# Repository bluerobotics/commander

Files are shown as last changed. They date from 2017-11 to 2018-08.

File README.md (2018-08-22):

# Commander

Blue Robotics Thruster Commander hardware and software: Thruster Test Jig Version.

Acceleration is limited more in this version than is usual.  Changing speed from stopped to full speed takes 2.0 seconds (as opposed to 0.8 seconds for the default firmware).

## Compiling and Uploading

The code can be compiled in the Arduino IDE version 1.0 and above. It requires the `attiny` board plugin by David Mellis, which can be installed with the Arduino Boards Manager. The following compile settings should be used:

- **Board:** ATtiny
- **Processor:** ATtiny84
- **Clock:** 8 Mhz (External)

- **Programmer:** USBTinyISP (or whatever you're using)

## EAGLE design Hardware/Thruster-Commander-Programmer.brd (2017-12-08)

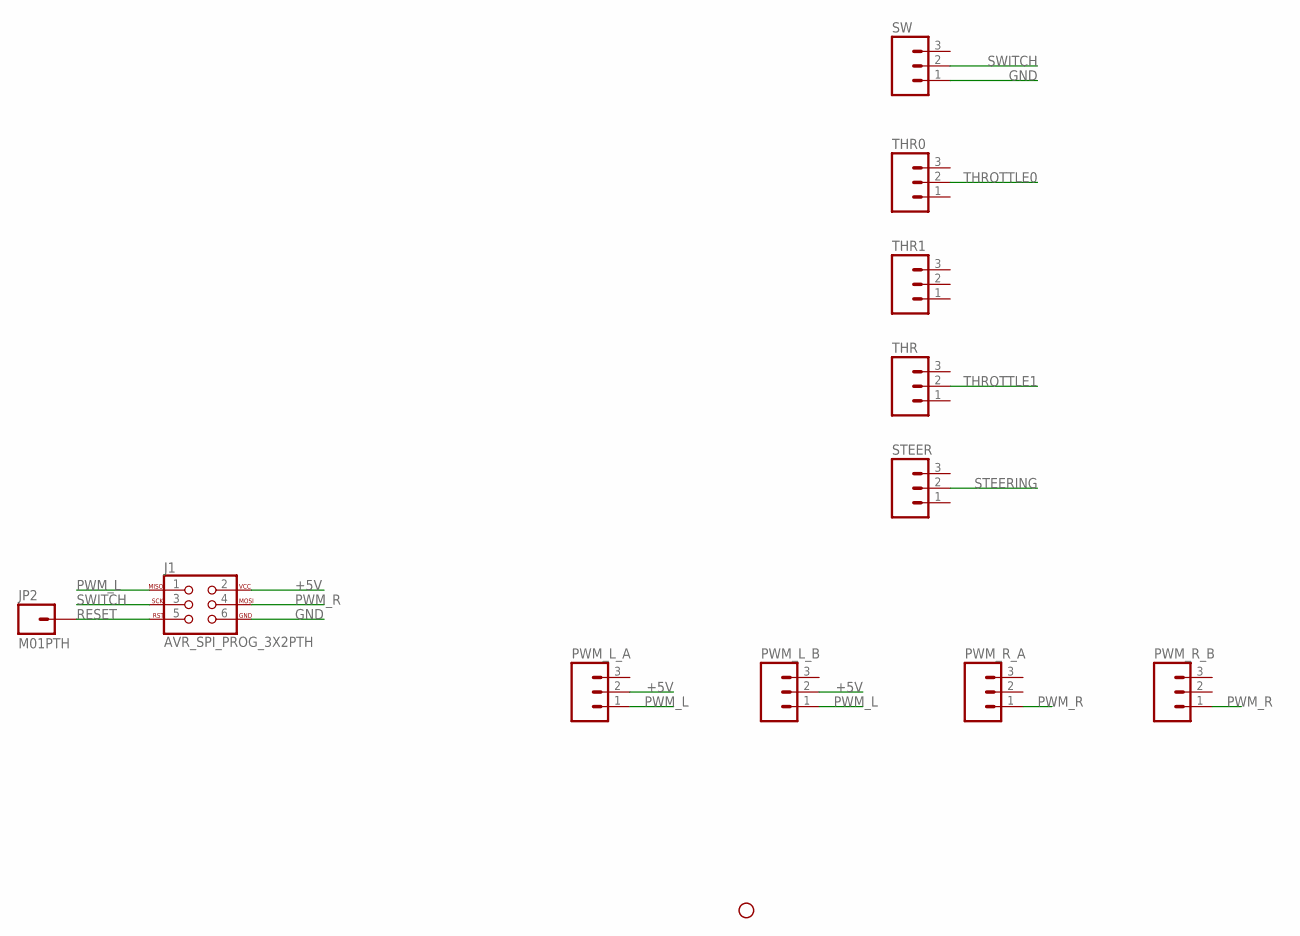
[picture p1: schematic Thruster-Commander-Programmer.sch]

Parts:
J1: AVR_SPI_PROG_3X2PTH; 2X3
JP2: M01PTH; 1X01
PWM_L_A: M03PTH; 1X03
PWM_L_B: M03PTH; 1X03
PWM_R_A: M03PTH; 1X03
PWM_R_B: M03PTH; 1X03
STANDOFF1: STAND-OFF
STEER: M03PTH; 1X03
SW: M03PTH; 1X03
THR, THR0, THR1: M03PTH; 1X03

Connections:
+5V: J1.2, PWM_L_A.2, PWM_L_B.2
GND: J1.6, SW.1
PWM_L: J1.1, PWM_L_A.1, PWM_L_B.1
PWM_R: J1.4, PWM_R_A.1, PWM_R_B.1
RESET: J1.5, JP2.1
STEERING: STEER.2
SWITCH: J1.3, SW.2
THROTTLE0: THR0.2
THROTTLE1: THR.2

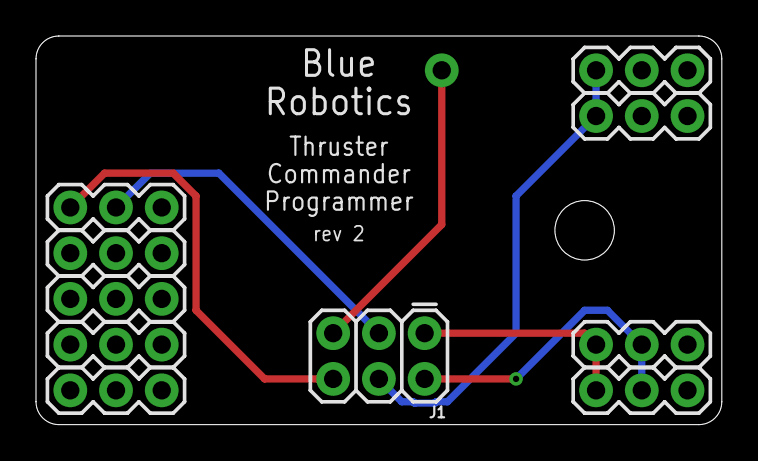
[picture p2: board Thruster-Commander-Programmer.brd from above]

Board: 2 copper layers, 38.1 x 21.6 mm, 12 parts (1 on the bottom side), 6 nets.

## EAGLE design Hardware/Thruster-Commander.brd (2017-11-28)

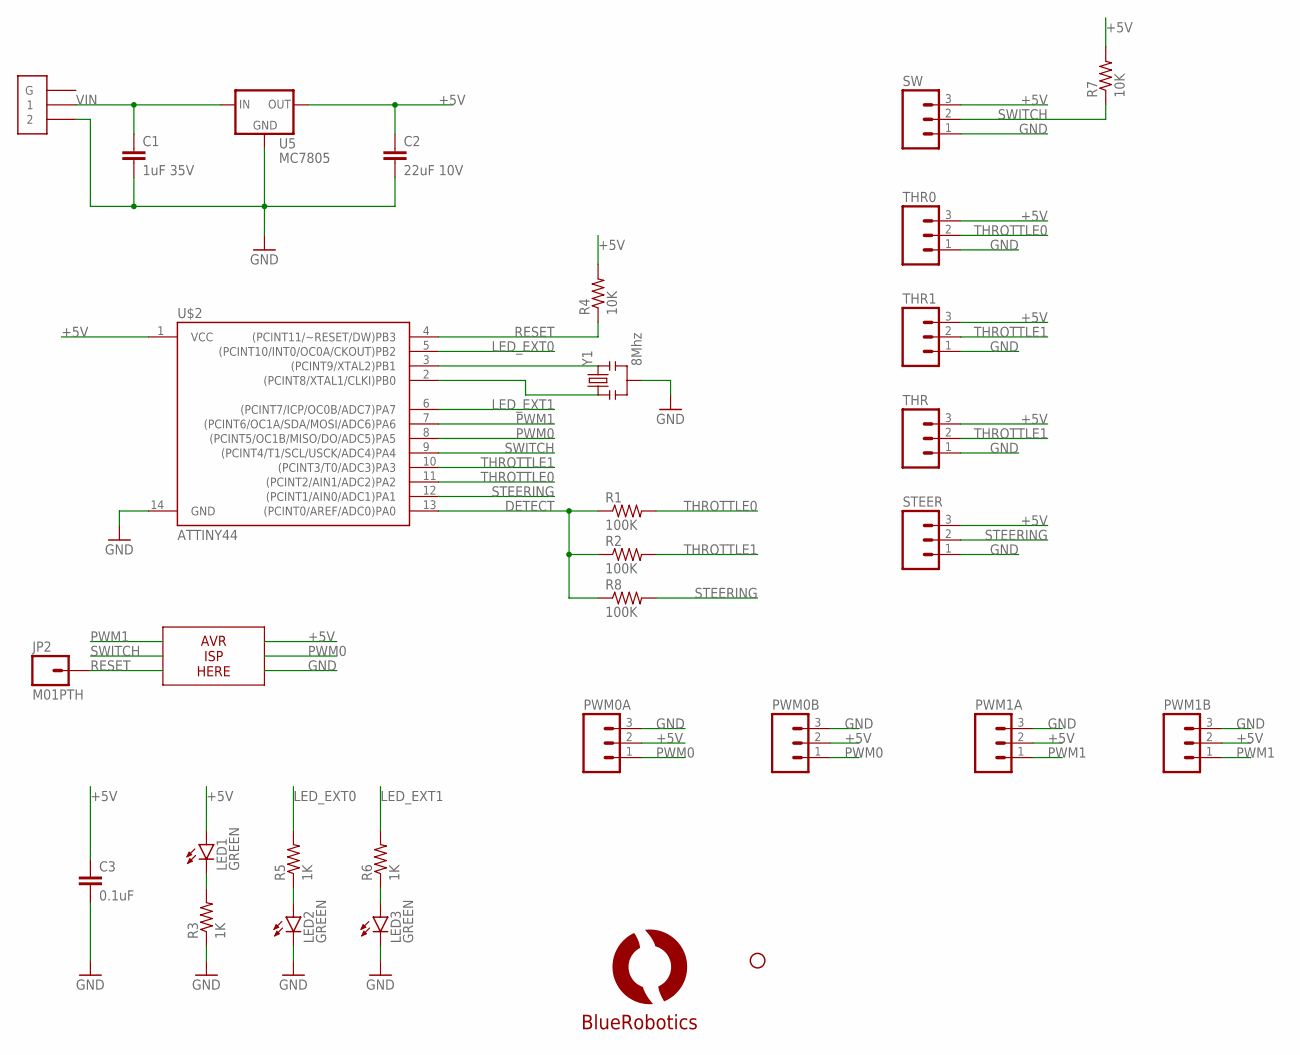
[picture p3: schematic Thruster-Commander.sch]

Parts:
C1: 1uF 35V; 0603-CAP
C2: 22uF 10V; 1206
C3: 0.1uF; 0603-CAP
JP2: M01PTH; 1X01
LED1, LED2, LED3: GREEN; LED-0603
PWM0A, PWM0B, PWM1A, PWM1B: M03PTH; 1X03
R1, R2, R8: 100K; 0603-RES
R3, R5, R6: 1K; 0603-RES
R4, R7: 10K; 0603-RES
STANDOFF1: STAND-OFF
STEER: M03PTH; 1X03
SW: M03PTH; 1X03
THR, THR0, THR1: M03PTH; 1X03
U5: MC7805; DPAK
U$1: LOGOBR-LOGO-MS; BR-LOGO-MEDIUM-SMALL
U$2: ATTINY44; SO14
U$3: JSH-GH-2VERT; JST-GH-TOP-2
Y1: 8Mhz; RESONATOR-SMD

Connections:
+5V: C2.1, C3.1, LED1.A, PWM0A.2, PWM0B.2, PWM1A.2, PWM1B.2, R4.2, R7.2, STEER.3, SW.3, THR.3, THR0.3, THR1.3, U5.3 (OUT), U$2.1 (VCC)
DETECT: R1.1, R2.1, R8.1, U$2.13 ((PCINT0/AREF/ADC0)PA0)
GND: C1.2, C2.2, C3.2, LED2.C, LED3.C, PWM0A.3, PWM0B.3, PWM1A.3, PWM1B.3, R3.1, STEER.1, SW.1, THR.1, THR0.1, THR1.1, U5.4 (GND), U$2.14 (GND), U$3.2, Y1.2
LED_EXT0: R5.2, U$2.5 ((PCINT10/INT0/OC0A/CKOUT)PB2)
LED_EXT1: R6.2, U$2.6 ((PCINT7/ICP/OC0B/ADC7)PA7)
unnamed: LED1.C, R3.2
unnamed: LED2.A, R5.1
unnamed: U$2.3 ((PCINT9/XTAL2)PB1), Y1.3
unnamed: U$2.2 ((PCINT8/XTAL1/CLKI)PB0), Y1.1
unnamed: LED3.A, R6.1
PWM0: PWM0A.1, PWM0B.1, U$2.8 ((PCINT5/OC1B/MISO/DO/ADC5)PA5)
PWM1: PWM1A.1, PWM1B.1, U$2.7 ((PCINT6/OC1A/SDA/MOSI/ADC6)PA6)
RESET: JP2.1, R4.1, U$2.4 ((PCINT11/~RESET/DW)PB3)
STEERING: R8.2, STEER.2, U$2.12 ((PCINT1/AIN0/ADC1)PA1)
SWITCH: R7.1, SW.2, U$2.9 ((PCINT4/T1/SCL/USCK/ADC4)PA4)
THROTTLE0: R1.2, THR0.2, U$2.11 ((PCINT2/AIN1/ADC2)PA2)
THROTTLE1: R2.2, THR.2, THR1.2, U$2.10 ((PCINT3/T0/ADC3)PA3)
VIN: C1.1, U5.1 (IN), U$3.1

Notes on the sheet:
AVR ISP HERE

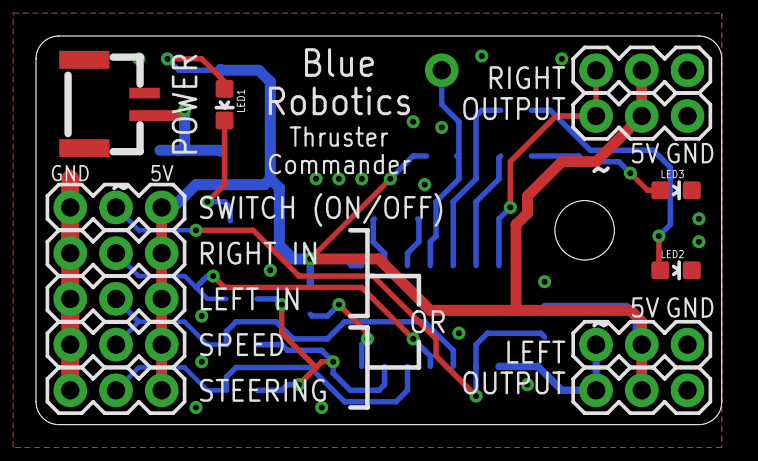
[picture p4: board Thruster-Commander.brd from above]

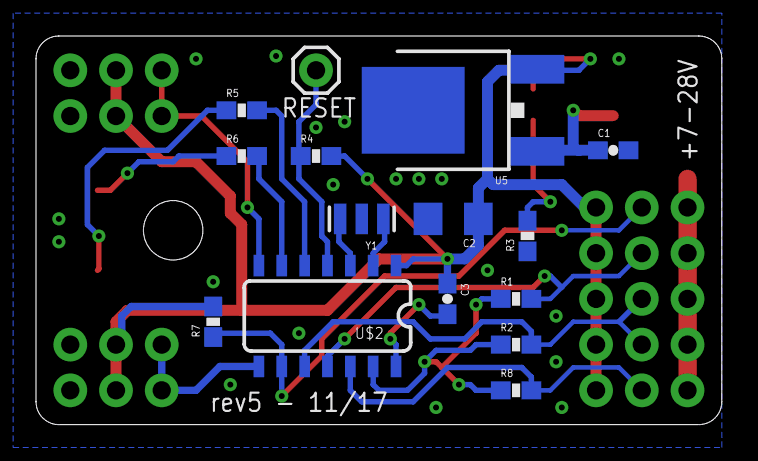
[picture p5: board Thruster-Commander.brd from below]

Board: 2 copper layers, 38.1 x 21.6 mm, 30 parts (15 on the bottom side), 18 nets.

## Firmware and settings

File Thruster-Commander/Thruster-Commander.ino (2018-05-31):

/* Blue Robotics Thruster Commander Firmware
-----------------------------------------------------

Title: Blue Robotics Thruster Commander Firmware

Description: This code is the default firmware for the Blue Robotics
Thruster Commander, which provides a simple interface to control a
bidirectional speed controller with PWM signals. It can be used to test
motors or to control simple vehicles like a kayak.

The code is designed for the ATtiny84 microcontroller and can be compiled and
uploaded via the Arduino 1.0+ software.

-------------------------------
The MIT License (MIT)

Copyright (c) 2017 Blue Robotics Inc.

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
THE SOFTWARE IS PROVIDED "AS IS", WITHOUT WARRANTY OF ANY KIND, EXPRESS OR
IMPLIED, INCLUDING BUT NOT LIMITED TO THE WARRANTIES OF MERCHANTABILITY,
FITNESS FOR A PARTICULAR PURPOSE AND NONINFRINGEMENT. IN NO EVENT SHALL THE
AUTHORS OR COPYRIGHT HOLDERS BE LIABLE FOR ANY CLAIM, DAMAGES OR OTHER
LIABILITY, WHETHER IN AN ACTION OF CONTRACT, TORT OR OTHERWISE, ARISING FROM,
OUT OF OR IN CONNECTION WITH THE SOFTWARE OR THE USE OR OTHER DEALINGS IN
THE SOFTWARE.
-------------------------------*/

#include "Thruster-Commander.h"

#include "Servo-Driver.h"
#include "Indicator.h"
#include "Limiter.h"

// Global Variable Declaration
bool      inLIsConnected, inRIsConnected, inSPDIsConnected, inSTRIsConnected;
Limiter   limiterL, limiterR;
uint32_t  lastpwmupdateruntime  = 0;
uint32_t  lastdetectruntime     = 0;


void setup() {
  // Set up pin modes
  pinMode(INPUT_L,INPUT);
  pinMode(INPUT_R,INPUT);
  pinMode(INPUT_SPD,INPUT);
  pinMode(INPUT_STR,INPUT);
  pinMode(SWITCH,INPUT);
  pinMode(DETECT,OUTPUT);
  pinMode(PWM_L,OUTPUT);
  pinMode(PWM_R,OUTPUT);
  pinMode(LED_L,OUTPUT);
  pinMode(LED_R,OUTPUT);

  // Initialize motor controllers
  initializePWMController();

  // Initialize LEDs
  initializeLEDs();
  writeBlinker(BLINK_S);

  // Initialize PWM acceleration limiters
  limiterL = Limiter(MAX_ACCEL, PWM_NEUTRAL);
  limiterR = Limiter(MAX_ACCEL, PWM_NEUTRAL);
}

void loop() {
  // Update PWM signals
  if ((millis() - lastpwmupdateruntime) > UPDATE_DT*1000) {
    int pwmL, pwmR, pwmSPD, pwmSTR;
    int pwmOutL, pwmOutR;
    int inputL, inputR, inputSPD, inputSTR, inputSWITCH;
    uint16_t errorPtrn = 0;

    // Record PWM update runtime
    lastpwmupdateruntime = millis();

    // Read switch
    inputSWITCH = digitalRead(SWITCH);

    // Read raw inputs
    inputL   = analogRead(INPUT_L);
    inputR   = analogRead(INPUT_R);
    inputSPD = analogRead(INPUT_SPD);
    inputSTR = analogRead(INPUT_STR);

    // Map standard inputs to 1000-2000 µs range
    pwmL   = map(inputL   - POT_OFFSET,0,1023,PWM_MIN,PWM_MAX);
    pwmR   = map(inputR   - POT_OFFSET,0,1023,PWM_MIN,PWM_MAX);
    pwmSPD = map(inputSPD - POT_OFFSET,0,1023,PWM_MIN,PWM_MAX);

    // Map steering to +/- steering range
    pwmSTR = map(inputSTR - POT_OFFSET,0,1023,-STEER_MAX,STEER_MAX);

    // Logic:
    // If SWITCH is pulled low (enabled):
    //   If both L and R are connected:
    //     L controls pwmOutL, R controls pwmOutR
    //   If both SPD and STR are connected:
    //     Mix SPD and STR to control pwmOutL and pwmOutR
    //   If only L is connected:
    //     L controls both pwmOutL and pwmOutR
    //   If only R is connected:
    //     R controls both pwmOutL and pwmOutR
    if (inputSWITCH == LOW) {
      if (inLIsConnected && inRIsConnected) {
        pwmOutL = pwmL;
        pwmOutR = pwmR;
      } else if (inSPDIsConnected && inSTRIsConnected) {
        pwmOutL = constrain(pwmSPD+pwmSTR,PWM_MIN,PWM_MAX);
        pwmOutR = constrain(pwmSPD-pwmSTR,PWM_MIN,PWM_MAX);
      } else if (inLIsConnected) {
        pwmOutL = pwmL;
        pwmOutR = pwmL;
      } else if (inRIsConnected) {
        pwmOutL = pwmR;
        pwmOutR = pwmR;
      } else {
        pwmOutL   = PWM_NEUTRAL;
        pwmOutR   = PWM_NEUTRAL;
        errorPtrn = BLINK_2S;
      }
    } else {
      pwmOutL   = PWM_NEUTRAL;
      pwmOutR   = PWM_NEUTRAL;
      errorPtrn = BLINK_1L;
    }

    // Limit acceleration
    pwmOutL = limiterL.step(pwmOutL);
    pwmOutR = limiterR.step(pwmOutR);

    // Set pwm outputs
    writePWM(PWM_L, pwmOutL);
    writePWM(PWM_R, pwmOutR);

    // Set LEDs
    if (errorPtrn == 0) {
      // No errors, display dimmer value
      writeDimmer(LED_L, pwmOutL);
      writeDimmer(LED_R, pwmOutR);
    } else {
      // display error pattern
      writeBlinker(errorPtrn);
    }

    return;
  }

  // Update detect
  if ((millis() - lastdetectruntime) > DETECT_DT*1000) {
    // Record detect runtime
    lastdetectruntime = millis();

    // Re-run detect()
    detect();

    return;
  }
}


void detect() {
  // Detect what's connected by driving lines through 100k resistors
  int inL[2], inR[2], inSPD[2], inSTR[2];   // 0:low, 1:high

  // Drive both inputs high, wait, and log values
  digitalWrite(DETECT,HIGH);
  delay(10);
  inL[1]   = analogRead(INPUT_L);
  inR[1]   = analogRead(INPUT_R);
  inSPD[1] = analogRead(INPUT_SPD);
  inSTR[1] = analogRead(INPUT_STR);

  // Drive both inputs low, wait, and log values
  digitalWrite(DETECT,LOW);
  delay(10);
  inL[0]   = analogRead(INPUT_L);
  inR[0]   = analogRead(INPUT_R);
  inSPD[0] = analogRead(INPUT_SPD);
  inSTR[0] = analogRead(INPUT_STR);

  // If inputs follow, potentiometer is disconnected, otherwise it's connected
  inLIsConnected   = !(inL[0]   < DETECT_LOW && inL[1]   > DETECT_HIGH);
  inRIsConnected   = !(inR[0]   < DETECT_LOW && inR[1]   > DETECT_HIGH);
  inSPDIsConnected = !(inSPD[0] < DETECT_LOW && inSPD[1] > DETECT_HIGH);
  inSTRIsConnected = !(inSTR[0] < DETECT_LOW && inSTR[1] > DETECT_HIGH);
}

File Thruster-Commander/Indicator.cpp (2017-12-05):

/* Blue Robotics Thruster Commander Firmware
-----------------------------------------------------

Title: Blue Robotics Thruster Commander Firmware - Indicator

Description: This code is the default firmware for the Blue Robotics
Thruster Commander, which provides a simple interface to control a
bidirectional speed controller with PWM signals. It can be used to test
motors or to control simple vehicles like a kayak.

The code is designed for the ATtiny84 microcontroller and can be compiled and
uploaded via the Arduino 1.0+ software.

-------------------------------
The MIT License (MIT)

Copyright (c) 2017 Blue Robotics Inc.

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
THE SOFTWARE IS PROVIDED "AS IS", WITHOUT WARRANTY OF ANY KIND, EXPRESS OR
IMPLIED, INCLUDING BUT NOT LIMITED TO THE WARRANTIES OF MERCHANTABILITY,
FITNESS FOR A PARTICULAR PURPOSE AND NONINFRINGEMENT. IN NO EVENT SHALL THE
AUTHORS OR COPYRIGHT HOLDERS BE LIABLE FOR ANY CLAIM, DAMAGES OR OTHER
LIABILITY, WHETHER IN AN ACTION OF CONTRACT, TORT OR OTHERWISE, ARISING FROM,
OUT OF OR IN CONNECTION WITH THE SOFTWARE OR THE USE OR OTHER DEALINGS IN
THE SOFTWARE.
-------------------------------*/

#include "Indicator.h"
#include "Thruster-Commander.h"

namespace {
uint16_t  pattern;
uint8_t   patternindex;
bool      blinking;
}

///////////////
// Functions //
///////////////

// Initialize LEDs for blinking mode, set bits to enable Fast PWM mode
void initializeLEDs() {
  // Note: timer0 clock source defaults to prescaler 64 (will run at 488 Hz)
  // Do not change!  Doing so will mess up millis(), etc, as they use timer0 too

  // Set Fast PWM mode
  bitSet(TCCR0A, WGM00);
  bitSet(TCCR0A, WGM01);

  // Start initialized for blinking
  setBlinkerBits();
  blinking = true;

  // Enable timer0 OCR0A compare interrupt (for blinking)
  bitSet(TIMSK0, OCIE0A);
}

// Set dimmer value
void writeDimmer(int pin, int pwm) {
  // Check whether we were previously in Blinker mode
  if (blinking) {
    // Stop blinking
    blinking = false;
    // Set up for dimming mode
    setDimmerBits();
  }

  // Stop interrupts while changing pwm settings
  cli();

  uint8_t period = constrain(map(abs(pwm - PWM_NEUTRAL), DEADZONE, HALF_RANGE,
                                 255, 0), 0, 255);   // 255 is off (inverting mode)

  if (pin == OC0A_PIN) {
    // Set timer0 Output Compare Register A
    // Set shut-off counter value to get pulsewidth us pulse
    OCR0A = period;
  }
  if (pin == OC0B_PIN) {
    // Set timer0 Output Compare Register B
    // Set shut-off counter value to get pulsewidth us pulse
    OCR0B = period;
  }

  // Done setting timers -> allow interrupts again
  sei();
}

// Set blink pattern
void writeBlinker(uint16_t ptrn) {
  // Check whether we were previously in Blinker mode
  if (!blinking) {
    // Start blinking
    blinking = true;
    // Set up for dimming mode
    setBlinkerBits();
    // Reset pattern index
    patternindex = 0;
  }

  // If pattern is different, reset index, save new pattern
  if (ptrn != pattern) {
    // Reset pattern index
    patternindex = 0;
    // Save new pattern
    pattern = ptrn;
  }
}

// Switch to dimmer mode by setting register bits
void setDimmerBits() {
  // Stop interrupts while changing timer settings
  cli();

  // Set inverting Fast PWM mode on A and B
  bitSet(TCCR0A, COM0A0);
  bitSet(TCCR0A, COM0A1);
  bitSet(TCCR0A, COM0B0);
  bitSet(TCCR0A, COM0B1);

  // Done setting timers -> allow interrupts again
  sei();
}

// Switch to blinker mode by setting register bits
void setBlinkerBits() {
  // Stop interrupts while changing timer settings
  cli();

  // Disable inverting Fast PWM mode on A and B
  bitClear(TCCR0A, COM0A0);
  bitClear(TCCR0A, COM0A1);
  bitClear(TCCR0A, COM0B0);
  bitClear(TCCR0A, COM0B1);

  // Done setting timers -> allow interrupts again
  sei();
}

///////////////////////////////
// Interrupt Service Routine //
///////////////////////////////

namespace {
uint16_t  isrcounter;
}

// Triggered every time OCR0A matches TIMER0 counter (488 Hz)
SIGNAL(TIM0_COMPA_vect) {
  isrcounter++;
  if (isrcounter >= 2*(F_CPU/64/256)/16) {
    isrcounter = 0;
    if (blinking) {
      digitalWrite(OC0A_PIN, bitRead(pattern, patternindex));
      digitalWrite(OC0B_PIN, bitRead(pattern, patternindex));
      if (patternindex < 15) {
        patternindex++;
      } else {
        patternindex = 0;
      }
    }
  }
}

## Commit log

2017-09-22 Initial files and readme.
    [Thruster-Commander.brd, Thruster-Commander.sch]
2017-10-05 Directly use timers to control PWM
2017-10-16 Correct midpoint offset on external pots
    [Thruster-Commander.h, Thruster-Commander.ino]
2017-10-16 rev3 version.
    [Thruster-Commander.brd, Thruster-Commander.sch]
2017-10-20 Updates to rev4.
    [Thruster-Commander.brd, Thruster-Commander.sch]
2017-10-20 Remove Servo-Driver test
2017-10-25 Add low-pass filters to pwm outputs
2017-11-03 rev5 hardware.
    [Thruster-Commander.brd]
2017-11-28 Minor updates.
    [Thruster-Commander.brd]
2017-11-28 Add programmer boards
    [Thruster-Commander-Programmer.brd, Thruster-Commander-Programmer.sch]
2017-11-30 Pin reassignment and function updates
2017-11-30 Change SWITCH to deadman mode
2017-11-30 Simplify filter
2017-11-30 Allow pot hot swap
    [LPFilter.cpp, Thruster-Commander.h, Thruster-Commander.ino]
2017-11-30 Use LED brightness to show speed, display errors as blink codes
    [Indicator.cpp, Servo-Driver.cpp, Thruster-Commander.h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]
2017-11-30 Filter harder
2017-12-05 Replace low-pass filter with acceleration limiter
    [Thruster-Commander.h, Thruster-Commander.ino]
2017-12-08 Fix programmer board MISO/MOSI connections
    [Thruster-Commander-Programmer.brd, Thruster-Commander-Programmer.sch]
2018-05-31 Fix errant pot detection when touching PCB
    [Thruster-Commander.h]
2018-08-22 Limit change in PWM to half range over 2 seconds (from 0.8)

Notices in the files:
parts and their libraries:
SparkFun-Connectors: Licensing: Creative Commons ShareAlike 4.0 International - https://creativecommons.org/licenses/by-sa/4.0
